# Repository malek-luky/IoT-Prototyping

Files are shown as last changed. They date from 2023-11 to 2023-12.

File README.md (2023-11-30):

# Smart Patient Monitoring System

## 34365 IoT Prototyping Fall 23, DTU

An innovative healthcare system designed to enhance patient safety and improve emergency response times, that utilizes pressure, humidity, and temperature sensors to comprehensively monitor sleep activities, handling real-time alerts to notify responsible personnel, ensuring swift response to potential emergencies. 

## Project Poster
Project poster

## Project schema
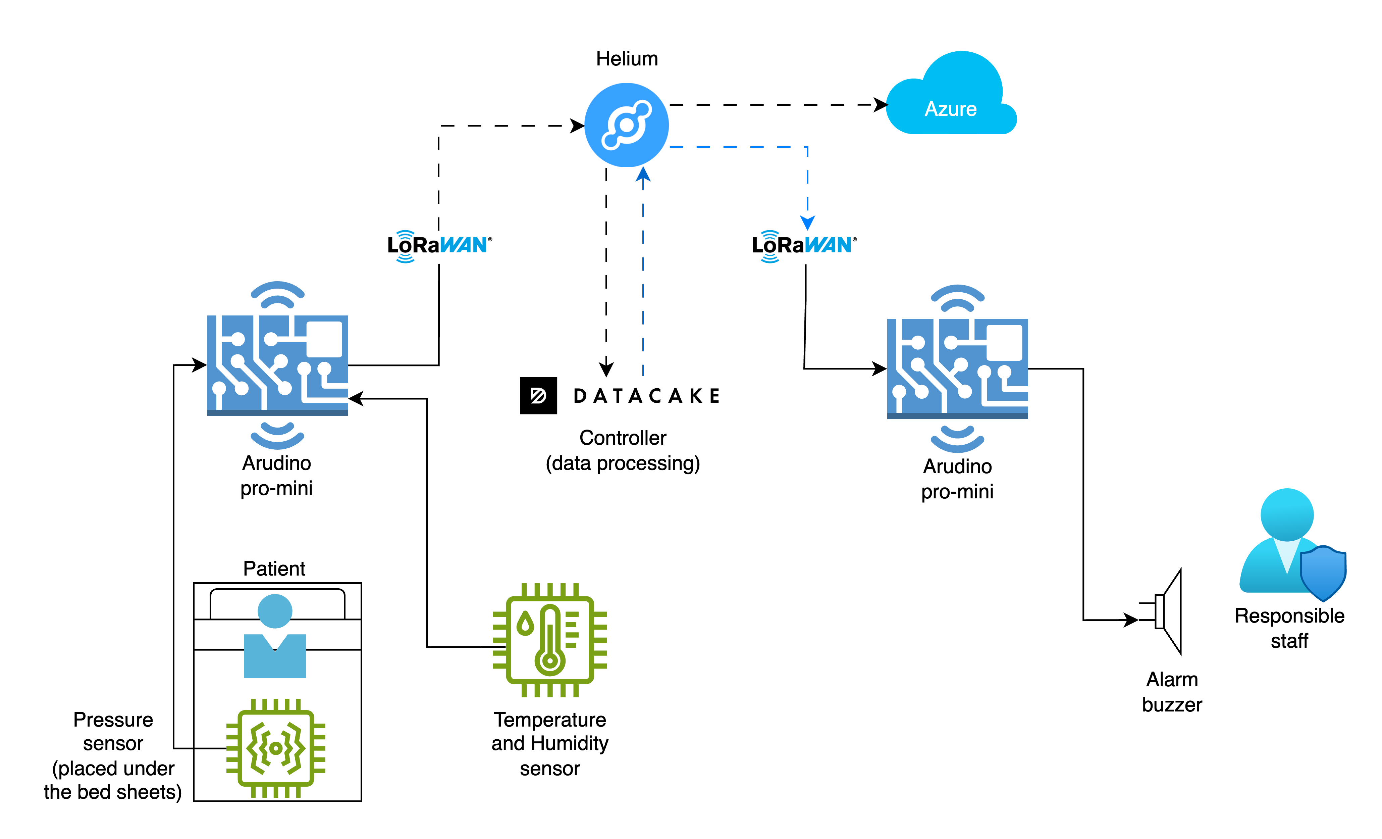
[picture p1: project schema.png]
Project schema


## Technical description

This project deploys a smart low-power easy-integrable patient monitoring system based on LoraWan communication with the help of RN2483 transceivers. The system can come in handy for hospitals/healthcare facilities, where patient real-time monitoring and safety are of the major importance. Day and night supervision of patients' activity with the emphasis of gathering statistics related to sleep flow is something that the system can offer and, hence, simplify the medical staff duties. It is desgined so, that every patient's bed is supplied with an FSR (pressure sensor) and, for the sake of indoors conditions monitoring, temperature & humidity DHT11 sensor. The data is reported in real time with adjustable frequency to Azure IoT Central and DataCake mobile dashboard, thus making it easy to analyze patient's activity in both desktop and mobile modes. In case a patient has left his/her bed for more than defined, regulable offset period (for current version of codes included in this project there is no offset period - sparing time for demonstration puproses), the system perceives such a patient as missing. If this is the case, cloud-based logic integrated with LoraWan backend starts sending immediate downlink notifications, trigerring the buzzer situated close to, for instance, duty nurse, who is expected to take action in finding the missing patient. Arduino Pro-Mini 3,3V, 8MHz of Arduino family is chosen as hosting micro-controller on both transmitter and receiver sides. While buzzer is signalling alarm, the button could be pressed for disabling the buzzer and put it on hold for a regulable period. That saves energy of the receiver and stops the noise produced by the buzzer. When the patient is back on his/her bed, the receiver will get notification automatically and, therefore, will no longer be in an "alarm mode".

## Built with
*  LoRaWAN
*  Helium
*  Datacake
*  Azure IoT Central
*  Arduino

# Authors
Dmytro Kirshev, Adam Rogowski, Vajk Olivér Vozári, Lukás Málek, Alberto Benito Pontes, Cesare Maio.

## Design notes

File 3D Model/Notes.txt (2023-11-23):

MAKE OUTSIDE SHELL BIGGER IN CURA!!!
EXPORT IN OBJ, BREP IN STL IS STILL COMPRESSED?

v3
65mm*X=66.75mm
X=66.75/65
X=102.7x bigger

v4
X=65.8/65 (two lines each side)
X=101.231x bigger

DO IT SO THAT LAYER HEIGHT IS DIVADABLE

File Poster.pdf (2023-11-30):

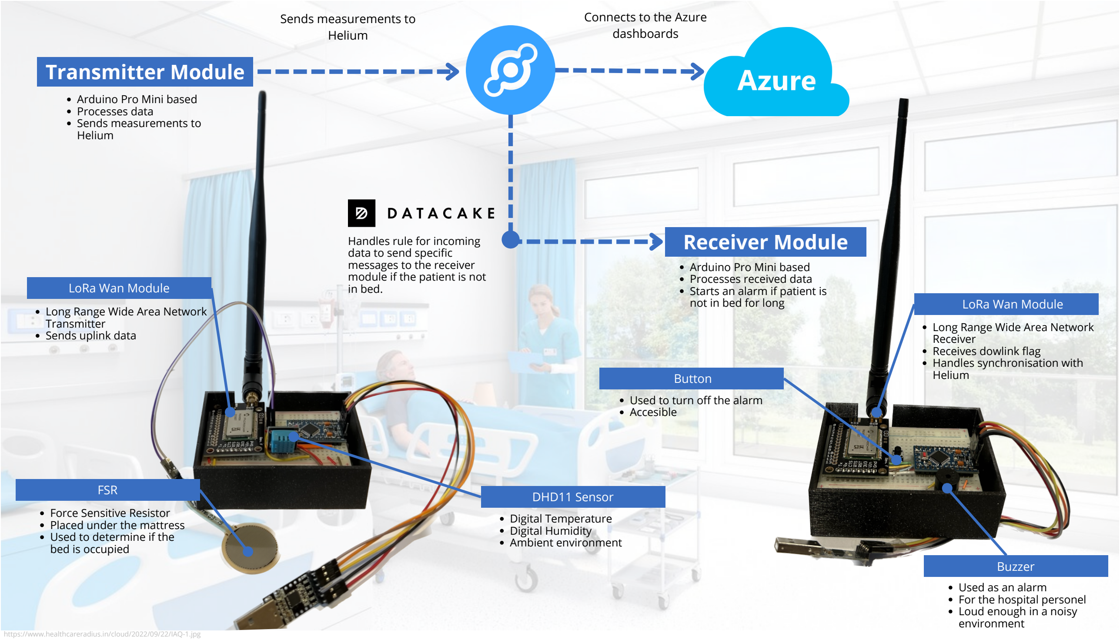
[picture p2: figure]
Button; Long Range Wide Area Network Receiver Receives dowlink flag Handles synchronisation with Helium; DHD11 Sensor; https://www.healthcareradius.in/cloud/2022/09/22/IAQ-1.jpg; Long Range Wide Area Network Transmitter Sends uplink data; Handles rule for incoming data to send specific messages to the receiver module if the patient is not; LoRa Wan Module; in bed.; Transmitter Module; FSR; Buzzer; Force Sensitive Resistor Placed under the mattress Used to determine if the bed is occupied; Sends measurements to Helium; Digital Temperature Digital Humidity Ambient environment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

# MMaarrkkeett

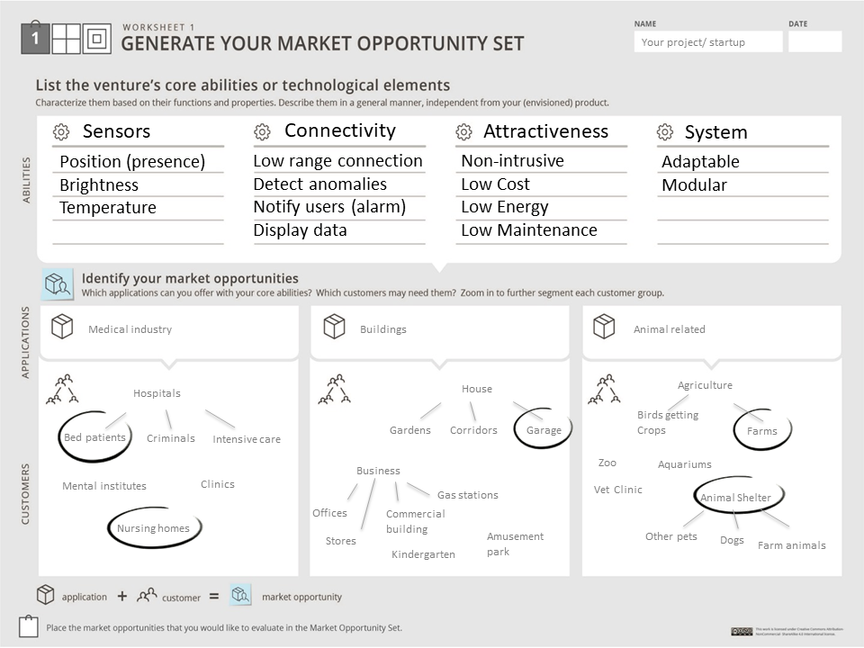
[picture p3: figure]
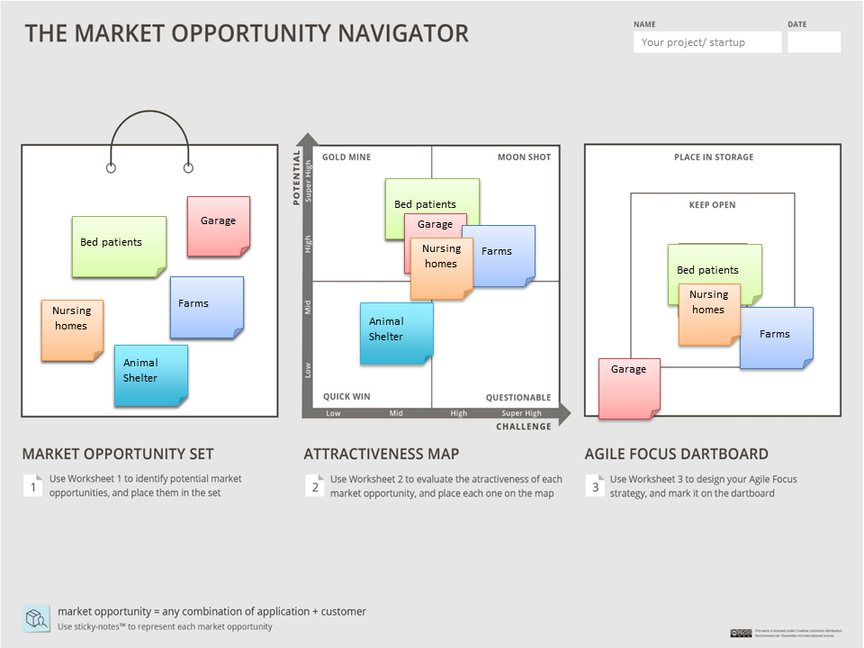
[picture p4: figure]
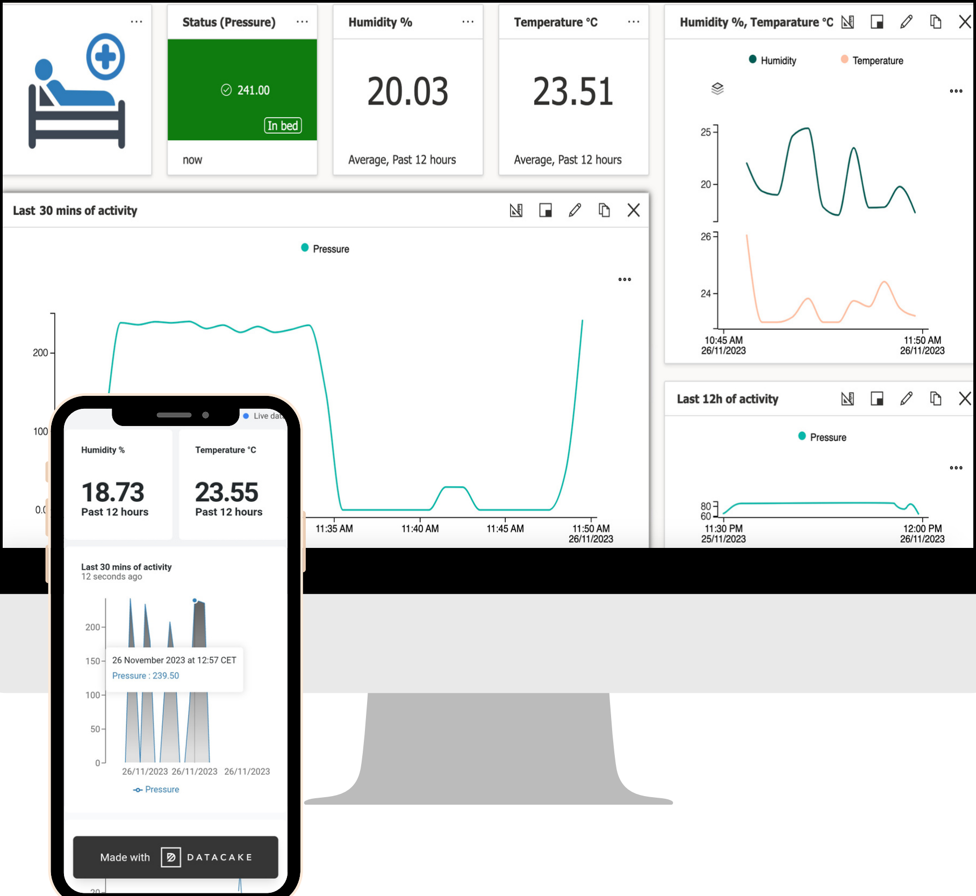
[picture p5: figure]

# Conclusions

# Smart Patient Monitoring System

An innovative healthcare system designed to enhance patient safety and improve emergency response times, that utilizes pressure, humidity, and temperature sensors to comprehensively monitor sleep activities, handling real-time alerts to notify responsible personnel, ensuring swift response to potential emergencies.

# User Interface

Adam Rogowski (232672), Alberto Benito Pontes (223068), Cesare Maio (232435), Dmytro Kirshev (232671), Lukas Malek (212074), Vajk Oliver Vozari (223173) 34365 IoT Prototyping, Technical University of Denmark

In bed/Out of bed status in real-time based on pressure sensor data Pressure, humidity and temperature real-time data
Line charts with data trends and sleep activity up to past 12h
Big fonts for most relevant data, colour-coded graphs, size and position of the dashboard parts following UX principles

### Scan Me!

Successful implementation of seamless communication protocols, enabling smooth data transfer and device interaction. Plug-and-play system with an intuitive interface, ensuring ease of use for both patients and medical staff.
Arduino Pro Mini chosen for its low power consumption, optimizing energy efficiency in our IoT Prototyping project for a smart patient application.
Features a bespoke 3D printed box for durability and customized functionality within the system.

What was accomplished:

Teton
Milestone
Sensative AB
No Isolation
Monsenso
Total addressable market for IoT: | Competitors:
43.66bn DKK
Healthcare IoT market size: 5.83bn DKK
IoT CAGR (2023-2028): 12.08%
IoT CAGR (2023-2028): 11.18%
Growth of 9.9bn DKK over 5 years

Integrating more sensors for comprehensive patient monitoring Data mining and advanced analysis for more accurate behavioural model Designing a smaller, custom PCB for improved efficiency and space optimization in the system.

Potential areas of development:

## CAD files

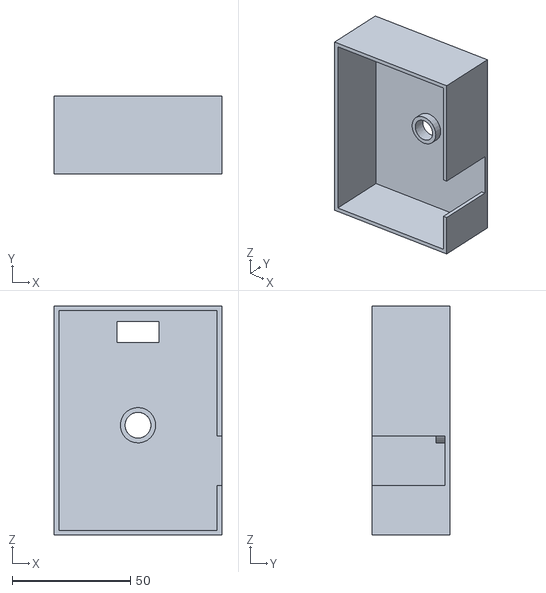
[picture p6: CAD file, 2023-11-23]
3D Model/v5/REceiver_Outside.obj
71.0 x 33.0 x 97.0

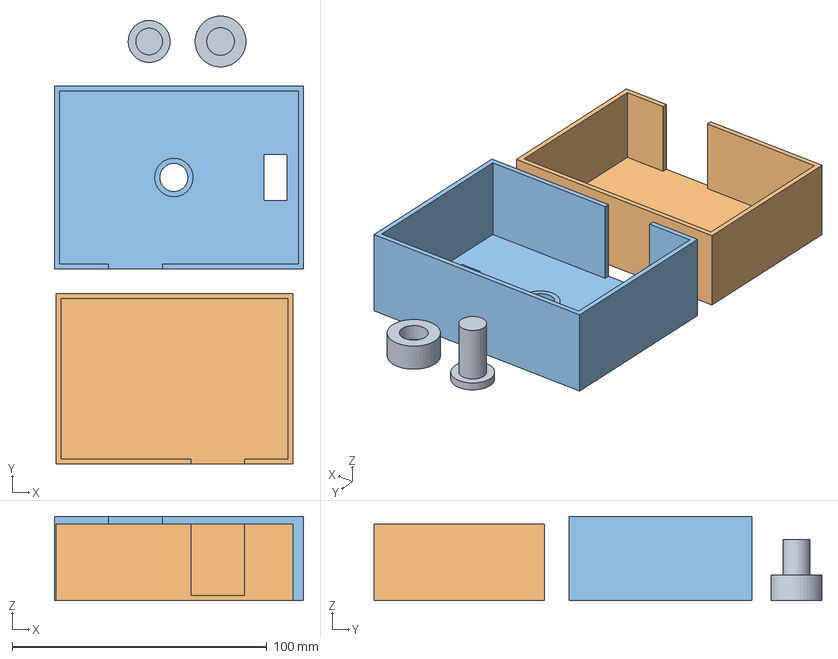
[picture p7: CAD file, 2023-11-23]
3D Model/v5/UM3E_REceiver_Button.3mf
97.8 x 175.9 x 33.0 mm
REceiver_Button.obj
REceiver_Inside.obj
REceiver_Outside.obj

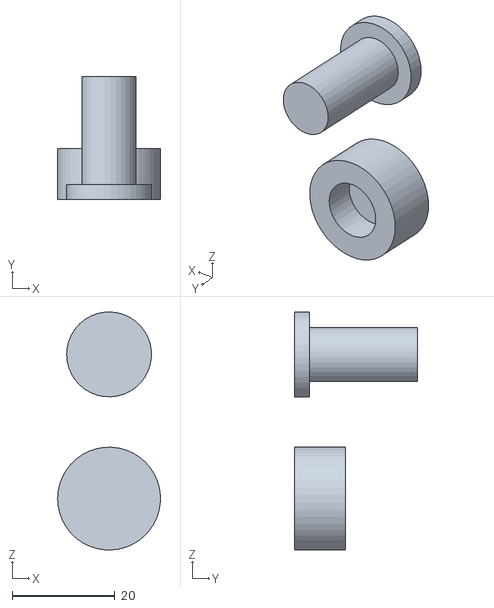
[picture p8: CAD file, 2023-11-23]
3D Model/v5/REceiver_Button.obj
20.0 x 24.0 x 46.3

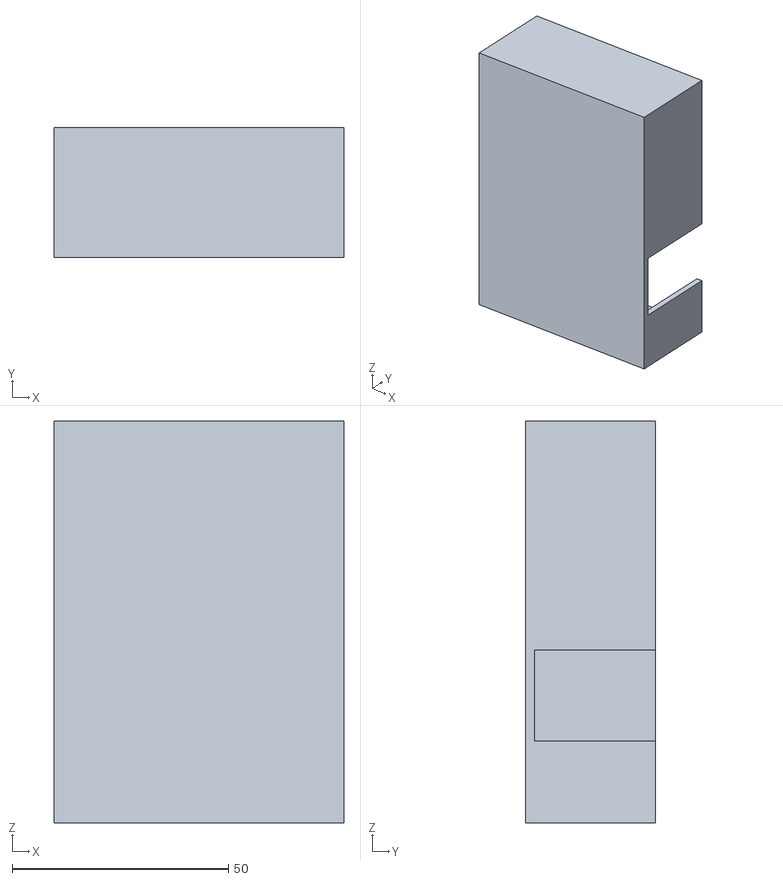
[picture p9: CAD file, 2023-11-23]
3D Model/v5/REceiver_Inside.obj
67.0 x 30.0 x 93.0

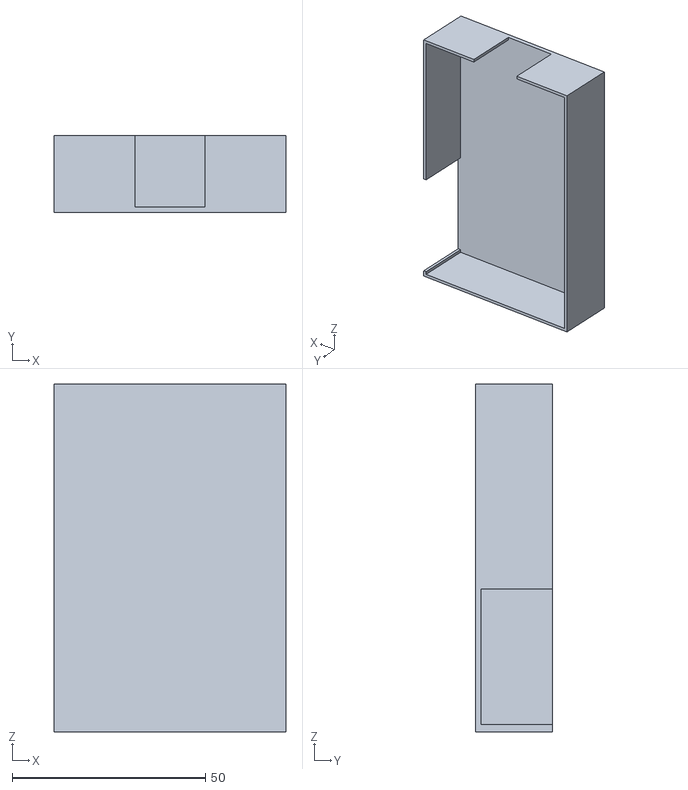
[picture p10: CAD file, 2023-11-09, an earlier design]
3D Model/v1/Inside.obj
60.0 x 20.0 x 90.0

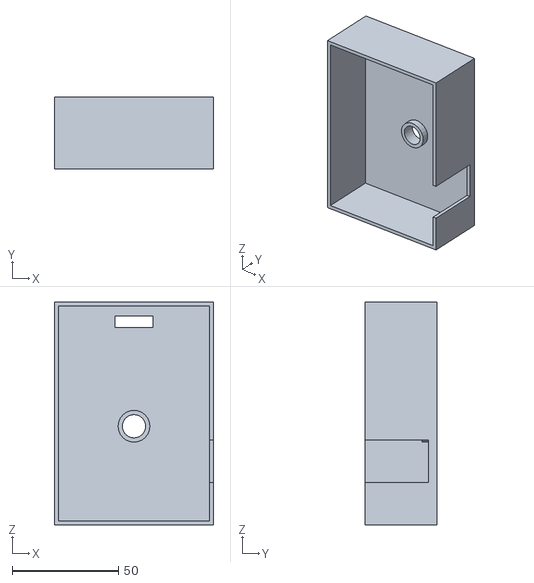
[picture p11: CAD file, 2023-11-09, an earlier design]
3D Model/v2/REceiver_Outside_3.stl
75.0 x 34.0 x 105.0

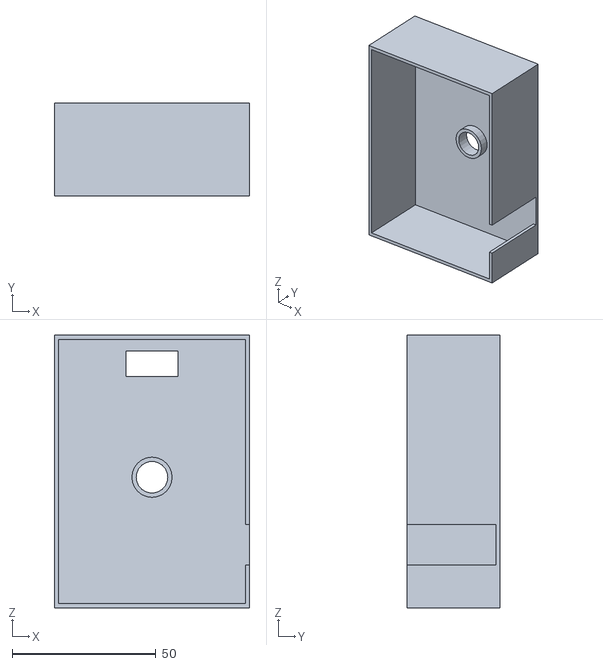
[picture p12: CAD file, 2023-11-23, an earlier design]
3D Model/v3/Outside.obj
68.0 x 32.5 x 95.0

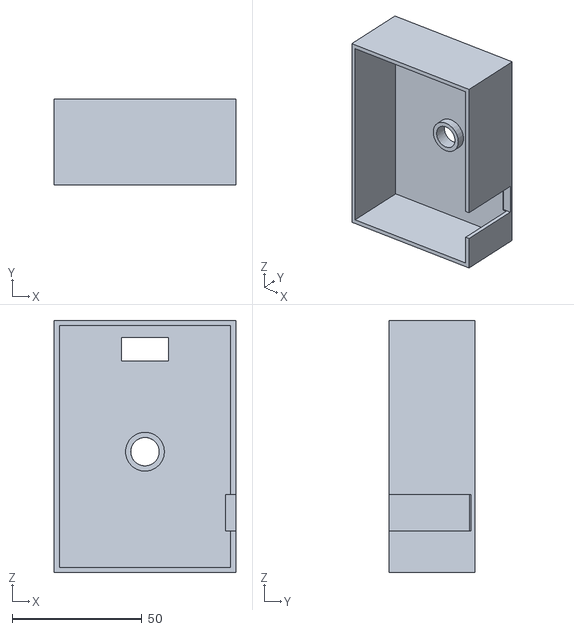
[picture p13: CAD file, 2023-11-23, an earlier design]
3D Model/v4/Outside.obj
70.0 x 33.0 x 97.0

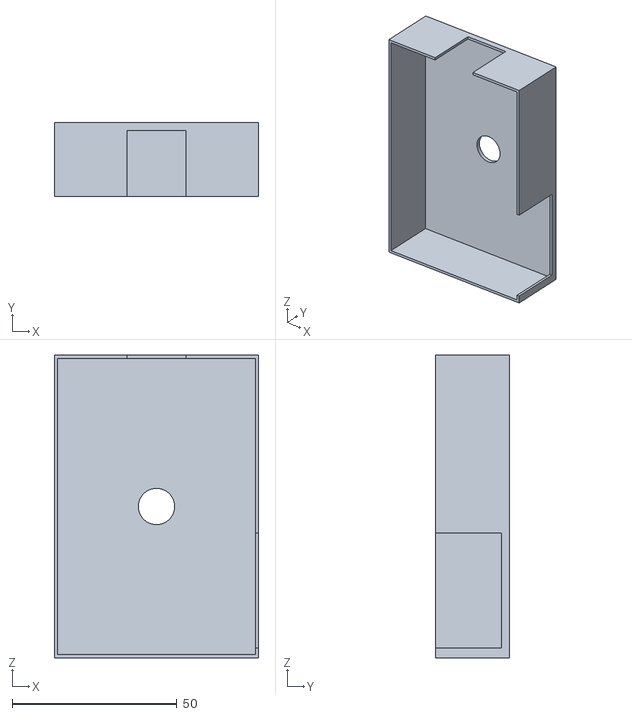
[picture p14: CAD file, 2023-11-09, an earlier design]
3D Model/v1/Outside.stl
62.0 x 22.5 x 92.0

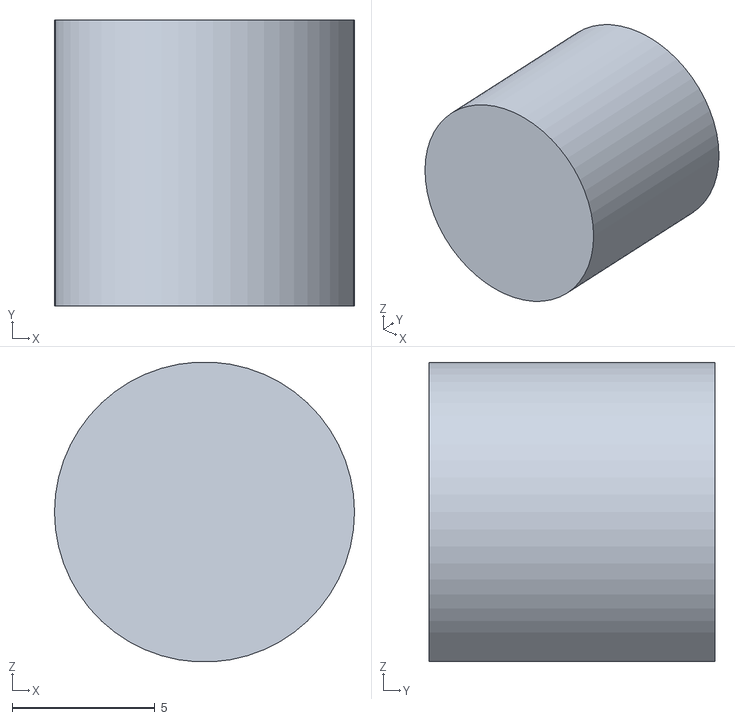
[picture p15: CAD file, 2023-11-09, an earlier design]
3D Model/v2/REceiver_Button_1.stl
10.5 x 10.0 x 10.5

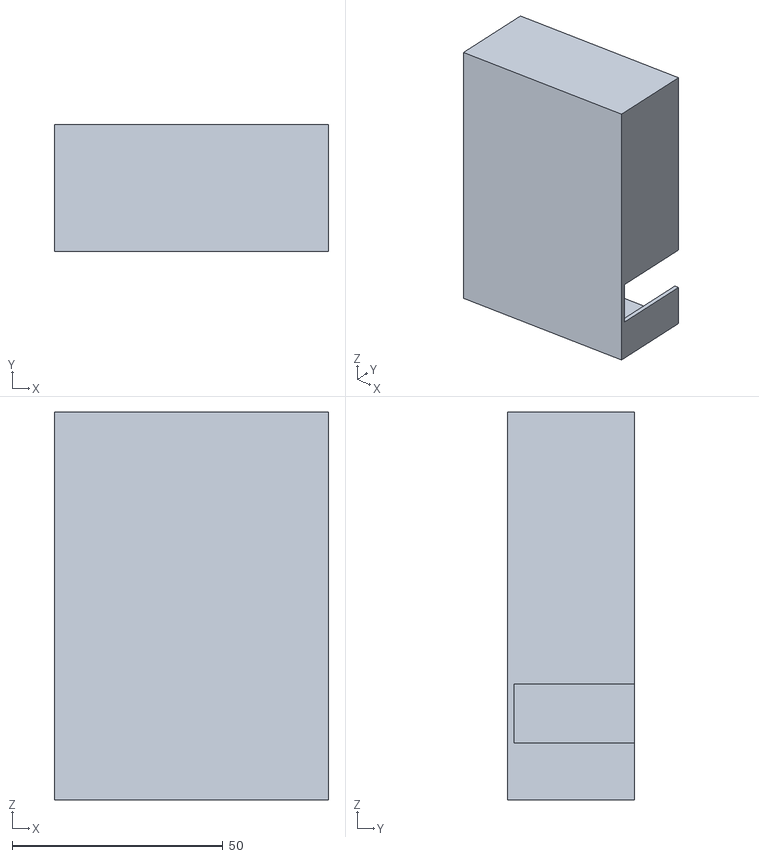
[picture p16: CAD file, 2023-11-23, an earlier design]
3D Model/v3/Inside.obj
65.0 x 30.0 x 92.0

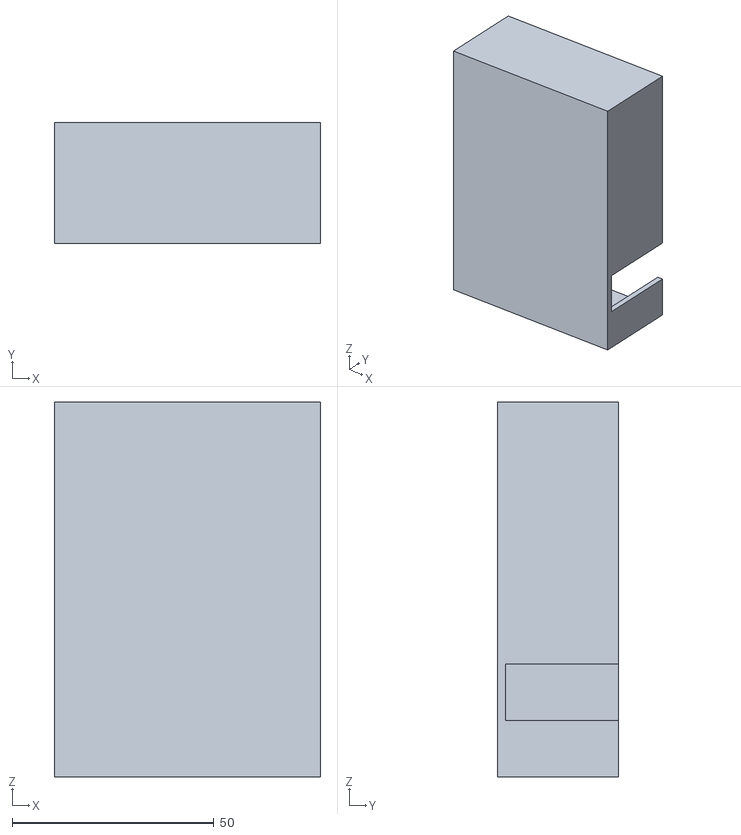
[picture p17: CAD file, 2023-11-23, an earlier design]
3D Model/v4/Inside.obj
66.0 x 30.0 x 93.0

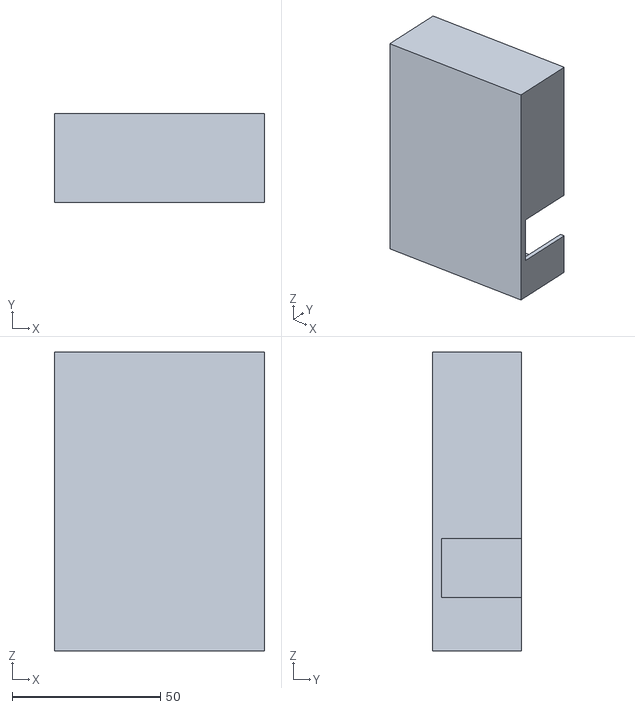
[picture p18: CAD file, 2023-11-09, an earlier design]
3D Model/v2/REceiver_Inside_2.stl
71.0 x 30.0 x 101.0

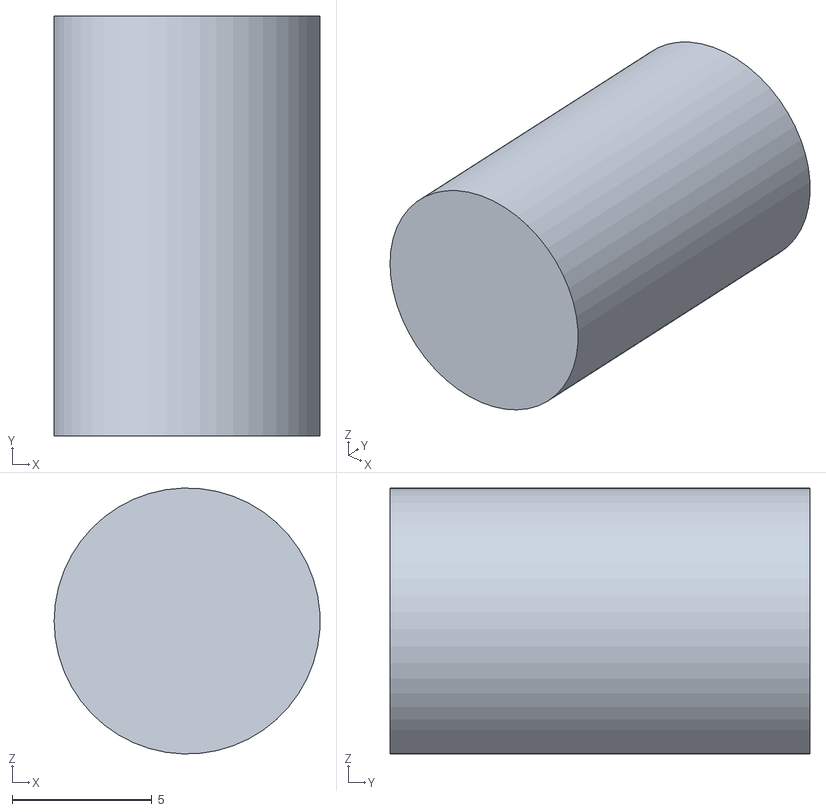
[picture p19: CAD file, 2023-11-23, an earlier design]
3D Model/v3/Button.obj
9.49 x 15.0 x 9.50

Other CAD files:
3D Model/v4/Button.obj
3D Model/v3/UM3E_Inside.3mf
3D Model/v4/UM3E_Inside.3mf
3D Model/OldVersions/REceiver.0010.ipt
3D Model/REceiver.iam
3D Model/REceiver.ipt
3D Model/v2/Button.ipt
3D Model/v2/Inside.ipt
3D Model/v2/Outside.ipt

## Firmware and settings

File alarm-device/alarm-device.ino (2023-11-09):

#include <rn2xx3.h>
#include <SoftwareSerial.h>

SoftwareSerial mySerial(10, 11);  // RX, TX
rn2xx3 myLora(mySerial);          //instance of the rn2xx3 library,

// Button + Buzzer
const int buttonPin = 13;
const int buzzerPin = A1;
int buttonState = 0;
bool alarmEnabled = false;
int incomingByte;

// Init Time
unsigned long currentTime;
unsigned long previousTime = 0;
unsigned long elapsedTime = 0;

/////////////////////////////////////////////////////////////////
/// SETUP
/////////////////////////////////////////////////////////////////
void setup() {
  Serial.begin(9600);    //serial port to computer
  mySerial.begin(9600);  //serial port to radio
  Serial.println("Startup");
  pinMode(buttonPin, INPUT_PULLUP);
  pinMode(buzzerPin, OUTPUT);
  initialize_radio();
  delay(2000);
}

/////////////////////////////////////////////////////////////////
/// RADIO INIT
/////////////////////////////////////////////////////////////////
void initialize_radio() {
  pinMode(12, OUTPUT);
  digitalWrite(12, LOW);
  delay(500);
  digitalWrite(12, HIGH);
  delay(100);  //wait for the RN2xx3's startup message
  mySerial.flush();
  myLora.autobaud();  //Autobaud the rn2483 module to 9600. The default would otherwise be 57600.

  //check communication with radio
  String hweui = myLora.hweui();
  while (hweui.length() != 16) {
    Serial.println("Communication with RN2xx3 unsuccessful. Power cycle the board.");
    Serial.println(hweui);
    delay(10000);
    hweui = myLora.hweui();
  }

  //print out the HWEUI so that we can register it via Heliumctl
  Serial.println("When using OTAA, register this DevEUI: ");
  Serial.println(myLora.hweui());
  Serial.println("RN2xx3 firmware version:");
  Serial.println(myLora.sysver());

  //configure your keys and join the network
  Serial.println("Trying to join Helium");
  bool join_result = false;
  const char *appEui = "6081F9D09104D7DA";                  // CHANGE HERE
  const char *appKey = "A30E1B3EABF7FCD62749DA00A703AD4A";  // CHANGE HERE
  join_result = myLora.initOTAA(appEui, appKey);

  while (!join_result) {
    Serial.println("Unable to join. Are your keys correct, and do you have Helium coverage?");
    delay(10000);  //delay a minute before retry
    join_result = myLora.init();
  }
  Serial.println("Successfully joined Helium");
}

void loop() {
  currentTime = millis();                    // Read current time
  elapsedTime = currentTime - previousTime;  // Calculate elapsed time

  /////////////////////////////////////////////////////////////////
  /// DOWNLINK
  /////////////////////////////////////////////////////////////////
  if (elapsedTime >= 10000) {              // If 10 second has passed, do the downlink
    String rnCommand = "mac tx uncnf 1 ";  // Creating tx command for RN2483 module. Unconfirmed tx on port 1
    mySerial.println(rnCommand);           // Sending command to RN2483 over serial connection
    while (mySerial.available() > 0)       // Checking if there is any serial data coming in from RN2483
    {
      int incomingByte = mySerial.read();  // Read the incoming bytes from RN2483 module, one by one:
      Serial.write(incomingByte);          // Writes out the byte as a readable ASCII character, one by one
    }
    previousTime = currentTime;  // Update time
  }

  /////////////////////////////////////////////////////////////////
  /// BUZZER
  /////////////////////////////////////////////////////////////////
  buttonState = digitalRead(buttonPin);  // Read button state


  // RECEIVER LOGIC
  if (incomingByte == 31) {
    if (alarmEnabled == false) {
      alarmEnabled == true;
      tone(buzzerPin, 1000);  // Play a default tone
    }
  }

  else if (incomingByte == 30) {
    alarmEnabled = false;
    noTone(buzzerPin);  // Stop the buzzer
  }

  else {
    Serial.println("Unknown Message Received");
  }

  // BUZZER LOGIC
  if (buttonState == LOW) {  // button pressed
    noTone(buzzerPin);       // Stop the buzzer
  }

  delay(100);  // Add a short delay for stability
}

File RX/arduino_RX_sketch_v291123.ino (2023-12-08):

/*
 * Author: Dennis Ruigrok and JP Meijers
 * Date: 2017-01-16
 *
 * This program is meant to be used with an Arduino UNO or NANO, conencted to an RNxx3 radio module.
 * It will most likely also work on other compatible Arduino or Arduino compatible boards,
 * like The Things Uno, but might need some slight modifications.
 *
 * Transmit a one byte packet via TTN, using confirmed messages,
 * waiting for an acknowledgement or a downlink message.
 *
 * CHECK THE RULES BEFORE USING THIS PROGRAM!
 *
 * CHANGE ADDRESS!
 * Change the device address, network (session) key, and app (session) key to the values
 * that are registered via the TTN dashboard.
 * The appropriate line is "myLora.initABP(XXX);" or "myLora.initOTAA(XXX);"
 * When using ABP, it is advised to enable "relax frame count".
 *
 * Connect the RN2xx3 as follows:
 * RN2xx3 -- Arduino
 * Uart TX -- 10
 * Uart RX -- 11
 * Reset -- 12
 * Vcc -- 3.3V
 * Gnd -- Gnd
 *
 * If you use an Arduino with a free hardware serial port, you can replace
 * the line "rn2xx3 myLora(mySerial);"
 * with     "rn2xx3 myLora(SerialX);"
 * where the parameter is the serial port the RN2xx3 is connected to.
 * Remember that the serial port should be initialised before calling initTTN().
 * For best performance the serial port should be set to 57600 baud, which is impossible with a software serial port.
 * If you use 57600 baud, you can remove the line "myLora.autobaud();".
 *
 */
#include <rn2xx3.h>
#include <SoftwareSerial.h>

const int buzzer = A1;
const int button = 8;
int buttonState = 0;
int buttonprevState = 0;
int buttonnextState = 0;

unsigned long startMillis = 0;  //some global variables available anywhere in the program
unsigned long currentMillis;
const unsigned long period = 60000; // 1 minute

bool buttonPushed = false;
bool buz_on_hold = false;

SoftwareSerial mySerial(10, 11); // LoRa serial RX, TX

//create an instance of the rn2xx3 library,
//giving the software serial as port to use
rn2xx3 myLora(mySerial);

// the setup routine runs once when you press reset:
void setup()
{
  pinMode(buzzer, OUTPUT);
  //output LED pin
  pinMode(button, INPUT_PULLUP);
  pinMode(13, OUTPUT);
  led_on();

  // Open serial communications and wait for port to open:
  Serial.begin(57600); //serial port to computer
  mySerial.begin(9600); //serial port to radio
  Serial.println("Startup");

  //establishing connection to backend
  initialize_radio();

  //transmit a startup message
  myLora.tx("TTN Mapper on TTN Enschede node");
  
  buttonprevState = digitalRead(button);
  buttonnextState = digitalRead(button);

  attachInterrupt(digitalPinToInterrupt(button), pushButton_ISR, CHANGE);  // use interrupt pin2 

}


void pushButton_ISR()
{

  buttonPushed = true;   // ISR should be as short as possible

}

void initialize_radio()
{
  //reset rn2483
  pinMode(12, OUTPUT);
  digitalWrite(12, LOW);
  delay(500);
  digitalWrite(12, HIGH);

  delay(100); //wait for the RN2xx3's startup message
  mySerial.flush();

  //Autobaud the rn2483 module to 9600. The default would otherwise be 57600.
  myLora.autobaud();

  //check communication with radio
  String hweui = myLora.hweui();
  while(hweui.length() != 16)
  {
    Serial.println("Communication with RN2xx3 unsuccesful. Power cycle the board.");
    Serial.println(hweui);
    delay(10000);
    hweui = myLora.hweui();
  }

  //print out the HWEUI so that we can register it via ttnctl
  Serial.println("When using OTAA, register this DevEUI: ");
  Serial.println(myLora.hweui());
  Serial.println("RN2xx3 firmware version:");
  Serial.println(myLora.sysver());

  //configure your keys and join the network
  Serial.println("Trying to join TTN");
  bool join_result = false;


  //OTAA connection credentials
  const char *appEui = "6081F924D81FE16F";
  const char *appKey = "0DE827BDA3DA6C775087F3793825B6AD";
  
  join_result = myLora.initOTAA(appEui, appKey);
  
  while(!join_result)
  {
    Serial.println("Unable to join. Are your keys correct, and do you have TTN coverage?");
    delay(60000); //delay a minute before retry
    join_result = myLora.init();
  }
  Serial.println("Successfully joined TTN");
  

}

// the loop routine runs over and over again forever:
void loop()
{
    currentMillis = millis();
    if(buttonPushed = true) {    //button interrupt function
      if(digitalRead(button) == LOW & buttonprevState == HIGH & buttonnextState == HIGH) {
          noTone(buzzer);
          buz_on_hold = true;
          startMillis = millis();
          }
    }
    
    if (currentMillis - startMillis >= period) { // check if 1 min passed --- !!!***regulable offset***!!!
             buz_on_hold = false;
    }
    buttonPushed = false;
   
    led_on();
    String received;
    myLora.tx("!");  //tx sync uplink message for opening rx window
    Serial.print("Received downlink: ");
    received = myLora.getRx();  //write received byte into string variable
    alarmON(); //rx data processing function
    led_off();
    delay(3000);
}
void alarmON() 
{
   if(myLora.getRx().length()==11) {
          Serial.println("PATIENT IS MISSING");
          if(!buz_on_hold) {
            tone(buzzer, 1000); // send 1KHz sound signal...
          }
     } else if(myLora.getRx().length()==3){
          noTone(buzzer);  // do not start the buzzer
          Serial.println("PATIENT IS ON HIS BED");      
     }
      
}


void led_on()
{
  digitalWrite(13, 1);
}

void led_off()
{
  digitalWrite(13, 0);
}

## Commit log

2023-11-06 Add alarm device functionality with button and buzzer
    a simple script that activate the buzzer and stops it when the button is pressed
    [alarm-device.ino]
2023-11-09 Added 3D Model
    [Button.ipt, Inside.ipt, Inside.obj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]
2023-11-16 Create arduino_TX_sketch_v161123
2023-11-16 Update and rename arduino_TX_sketch_v161123 to arduino_TX_sketch_v161123.ino
2023-11-23 Added 3D Print + Buzzer Demo
    [Button.obj, Inside.obj, Outside.obj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]
